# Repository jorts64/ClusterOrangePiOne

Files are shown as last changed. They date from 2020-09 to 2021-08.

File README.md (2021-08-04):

# Cluster Orange Pi One
Un Cluster [molt econòmic](bom.md) ( < 150 € ) utilitzant 7 [Orange Pi One](http://www.orangepi.org/orangepione/) amb [armbian](armbian.md). 

Aquest cluster el farem servir des d'un ordinador amb jupiter notebook

Utilitzem una torre vella de PC amb una font [ATX](img/ATX.jpg). Cada Orange Pi One va en una [safata](openscad/bandeja3p5OrangePiOne.stl) d'unitat 3.5" impressa en 3D dissenyada en [OpenSCAD](openscad/bandeja3p5OrangePiOne.scad) i té 6 leds connectats al seu connector [GPIO](img/OrangePiGpioConnector.png).

## Instal·lació a l'ordinador principal

Veure [instruccions](jupyter.md)

## Instal·lació a les plaques Orange Pi One

Cal fer 3 passos amb cada placa del cluster (canvieu el hostname *cluster1* per la placa que esteu treballant):

* Instal·lar armbian [Instruccions](armbian.md)
* Instal·lar les llibreries per treballar amb Jupyter [Instruccions](pythonlib.md)
* Instal·lar MPI [Instruccions](mpi4py.md)

També teniu disponible un [soport](openscad/ledsCluster.stl) pels 7 mòduls de leds dissenyat amb [openSCAD](openscad/ledsCluster.scad)

## Muntatge del conjunt

Podeu veure aquesta [galeria d'imatges](muntatge.md) del procés de muntatge

## Posada en funcionament

Una vegada tot a punt, he obert tres terminals a l'ordinador principal:

1r terminal: iniciem controlador del cluster

    ./clusterM

2n terminal: iniciem serveis computació paral·lela a les targetes Orange Pi One

    ./clusterS

3r terminal: iniciem Jupyter notebook

    cd ~/jupyter
    jupyter notebook

Jo he provat un [càlcul de pi pel mètode de Montecarlo](jupyter/parallel01.ipynb)    
Ha anat força bé: 320 millions de assatjos en 80s no es veu cada dia!

# Actualització agost 2021

Aquests dies de vacances he aprofitat per tornar al meu clúster d'orange pi. He afegit sortides de 5V i 12 V amb amperímetre, ventiladors, monitors de càrrega i de temperatura:

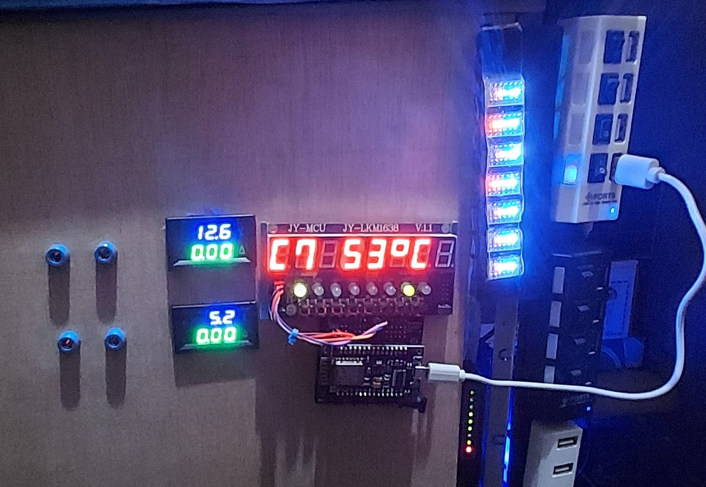
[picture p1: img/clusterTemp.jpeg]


## Monitors de càrrega
El programa [loadled.py](python3/loadled.py) es crida cada minut per [crontab](crontab/loadled) i actualitza els leds segons la càrrega de la placa orange pi.

## Monitor de temperatura
El programa [sendtemp](usrlocalbin/sendtemp) es crida cada minut per [crontab](crontab/sendtemp) i envia les dades a una placa NodeMCU ESP8266 programada amb codi [arduino](arduino/ClusterTemp.ino) amb una interfície basada en dígits de 7 segments, leds bicolors i polsadors.

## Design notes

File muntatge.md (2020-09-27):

# Muntatge del cluster

He fet servir una bella torre de PC amb font ATX. He afegit alguns connectors USB, sempre es necessiten! ( i el de color negre va a 5VSB, que sempre funciona fins-i-tot amb la font en standby)

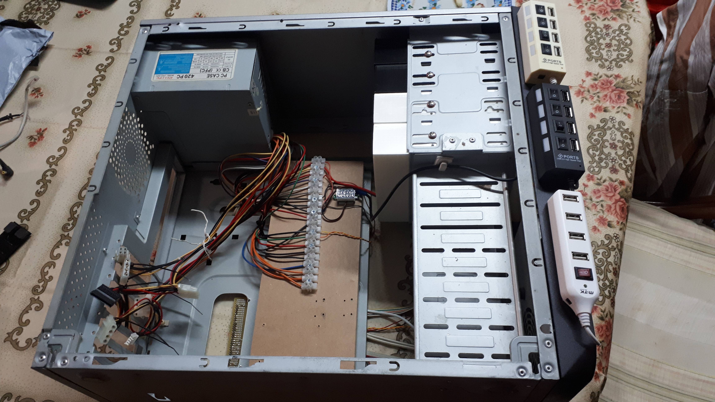
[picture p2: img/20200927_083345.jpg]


He tallat el connector de la motherboard i connectat els cables amb regletes de 10 A

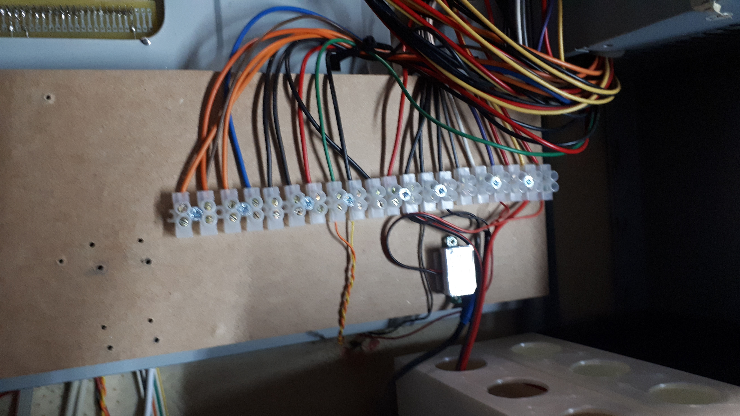
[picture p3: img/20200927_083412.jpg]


La font ens dona 36A a 5V, perfecte pel nostre projecte. Altres tensions seran útils per a altres usos de la capsa. Això si, caldra connectar un interruptor entre GND i el cable verd per controlar la font.

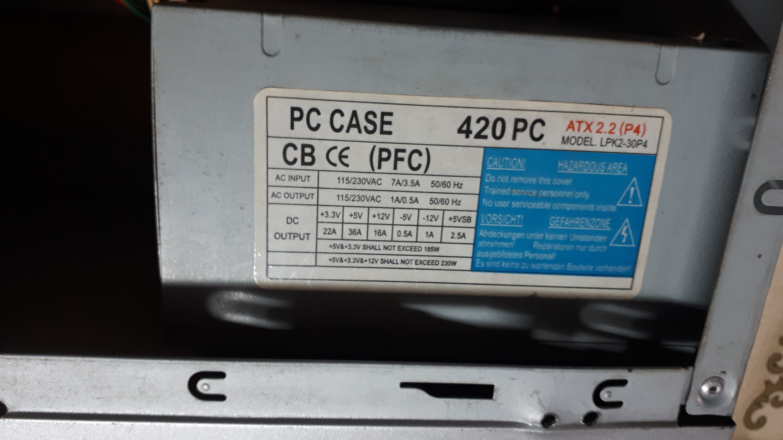
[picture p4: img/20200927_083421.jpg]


Cada placa Orange Pi One té el seu cable d'alimentació (que tallarem per connectar a la regleta) i la seva cinta per connectar el mòdul de leds.

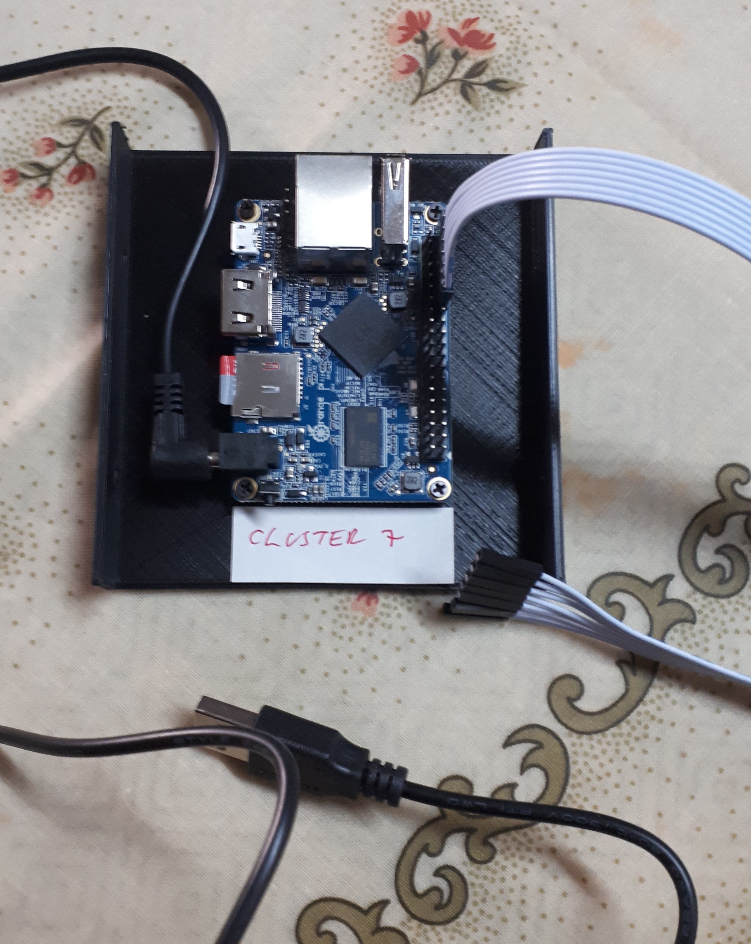
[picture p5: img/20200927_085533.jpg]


Els mòduls de leds van col·locats a una de les tapes, aquesta impressa en 3D

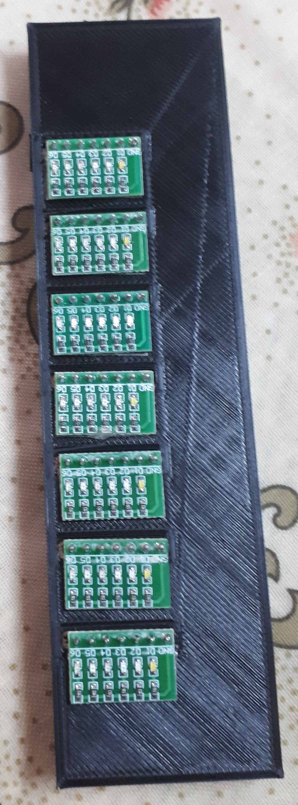
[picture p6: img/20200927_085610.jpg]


Preparem totes les plaques amb el programari instal·lat a la seva SD i els seus cables

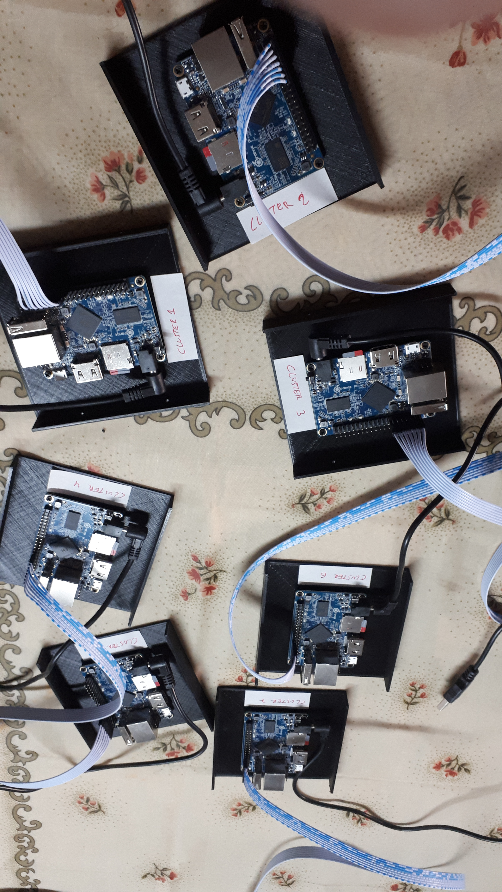
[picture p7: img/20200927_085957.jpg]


El switch va enganxat a una altra tapa, aquesta de fusta, amb cables de 1m

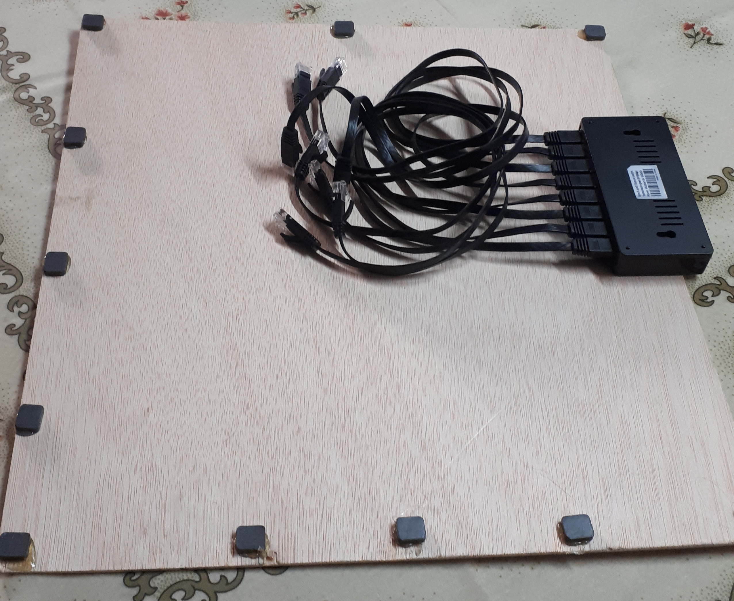
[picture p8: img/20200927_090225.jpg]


El switch sobresurt una mica de la tapa de fusta per mostrar els seus leds. També preparem un cable per connectar a 5V l'alimentació

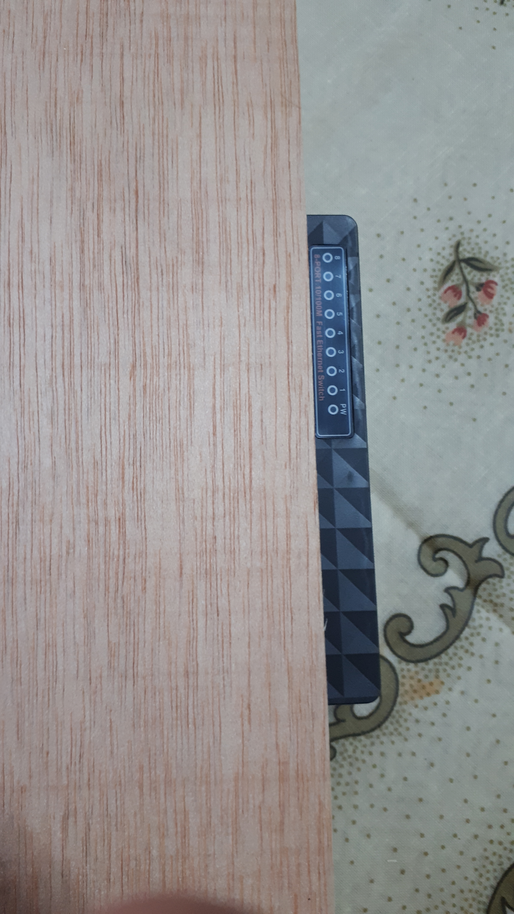
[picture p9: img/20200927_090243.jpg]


Connectem cada tarja al switch i fixem el conjunt amb cargols M3

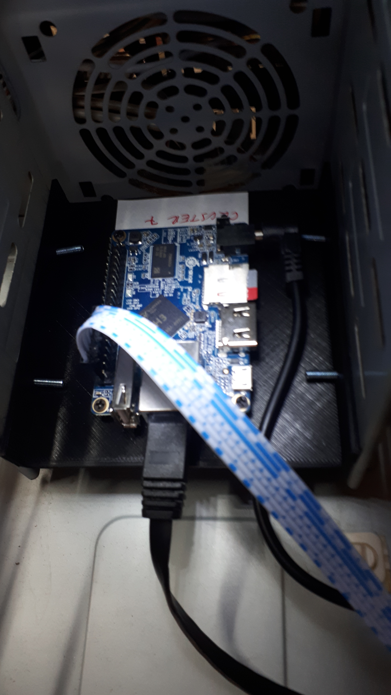
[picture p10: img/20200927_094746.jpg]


Connectem les alimentacions de les plaques i el switch en grups de 4 a les regletes (4x2A=8A < 10A)

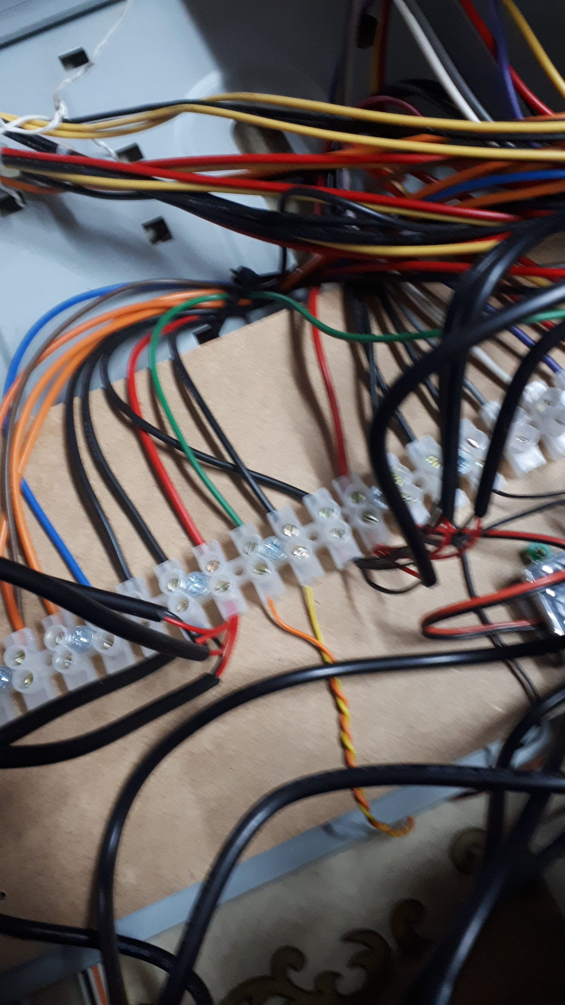
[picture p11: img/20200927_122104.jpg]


Una vegada fixades totes les plaques ordenem una mica el conjunt

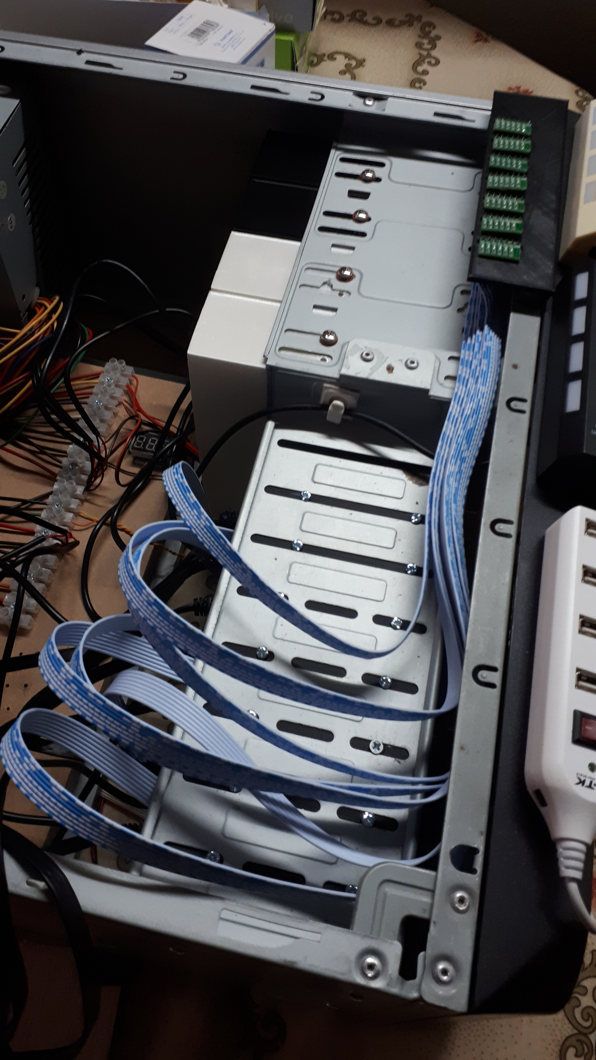
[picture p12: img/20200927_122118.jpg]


He aprofitat les bahies de 5" per posar uns calaixos impresos en 3D per a eines, i fins i tot una connexió de 12V per dremels i altres eines i instruments.

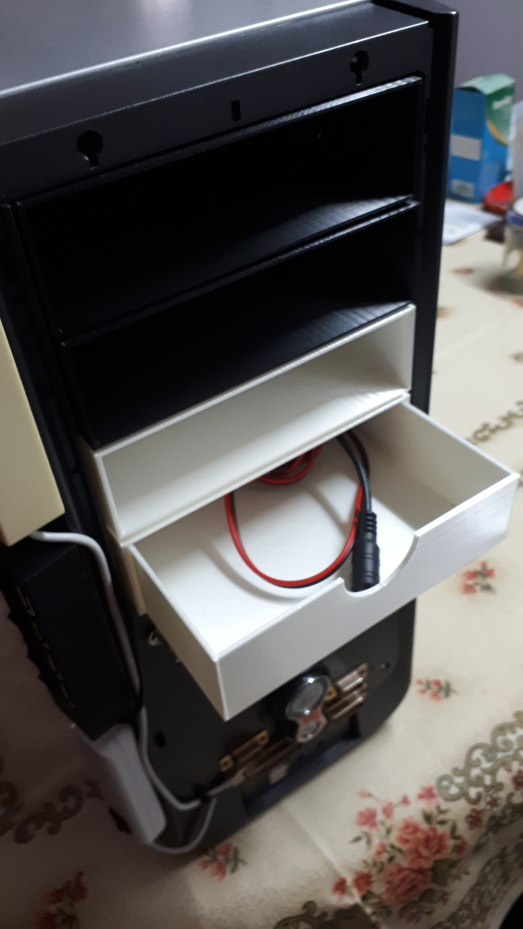
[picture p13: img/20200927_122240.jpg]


Finalment connectem a la xarxa i a 220V, engegem el sistema i tot funciona perfecte.

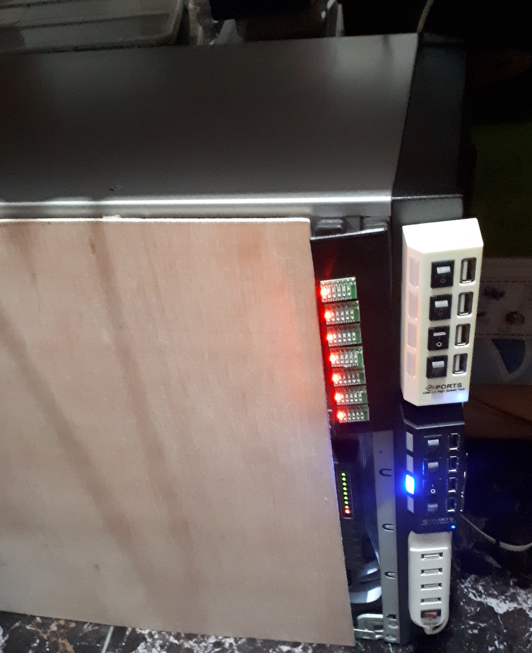
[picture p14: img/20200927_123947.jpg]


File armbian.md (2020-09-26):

# Instal·lació d'armbian a les plaques Orange Pi One

He utilitzat [armbian](https://www.armbian.com/orange-pi-one/) 20.05.2 basada en Buster (Debian 10), però baixant la versió actual hauria de funcionar igual.

Una vegada restaurada la imatge a una SD de 32 GB (jo he utilitzat l'eina Discs del meu Ubuntu) la posem a l'Orange Pi one i connectem la placa a la xarxa i aun carregador USB de 2A.

Localitzem a la xarxa quina IP ha agafat la placa (en el meu cas 192.168.1.136)

Ens connectem a la placa per xarxa des d'un terminal (contrasenya de *root* **1234**)

     ssh root@192.168.1.136

Ens obliga a canviar la contrasenya de *root* i crear un nou usuari. En el meu cas he creat l'usuari *jordi*, el mateix que faig servir a la meva màquina principal.

Actualitzem els paquets

     apt update
     apt upgrade

Instal·lem *mc*

    apt install mc

Configurem el sistema amb

    armbian-config
    
A *Personal settings -> Timezone* canviem el fus horari

A *Personal settings -> Hostname* canviem el nom de la màquina per *cluster1*

A *System -> Hardware* activem el bus GPIO **w1-gpio**

Reiniciem el sistema

    reboot
    
Ens tornem a connectar com a *root* i seguint les instruccions de [https://orangepiweb.es/gpio.php](https://orangepiweb.es/gpio.php) preparem el port GPIO per a python3:

    apt install python3-dev python3-setuptools swig python3-pip python3-wheel 
    git clone https://github.com/zhaolei/WiringOP.git -b h3
    cd WiringOP
    ./build
    cd ..
    git clone https://github.com/duxingkei33/orangepi_PC_gpio_pyH3.git
    cd orangepi_PC_gpio_pyH3/
    python3 setup.py install
    
Ara podem veure l'estat del GPIO amb 

    gpio readall

Però el nom dels pins que hem de fer servir amb aquesta llibreria de Python són aquests que veieu en color verd:

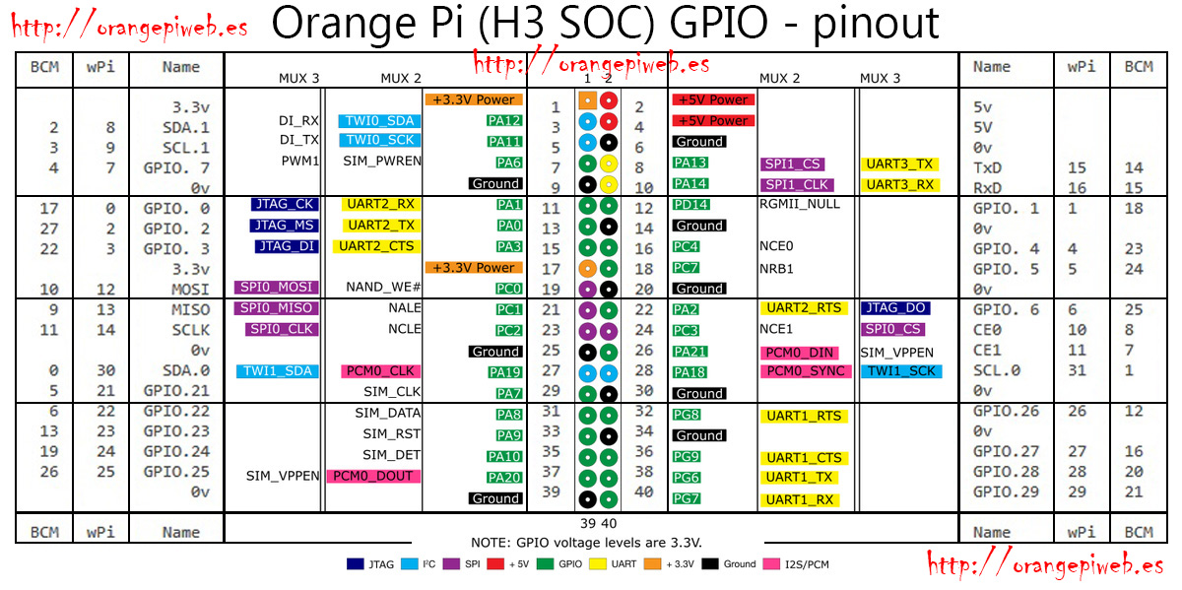
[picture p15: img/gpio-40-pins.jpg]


Ja podeu connectar el mòdul de 6 leds als pins senars 27-39 del connector i provar l'exemple [testleds.py](python3/testleds.py). Potser us caldrà abans fer una altra vegada reboot.

    cd ..
    wget https://raw.githubusercontent.com/jorts64/ClusterOrangePiOne/master/python3/testleds.py
    chmod u+x testleds.py
    ./testleds.py

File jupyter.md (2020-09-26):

# Instal·lació de jupyter notebook a l'ordinador principal

Aquesta instal·lació l'he comprovada amb Debian 10. és important escollir aquesta distribució per compatibilitat amb el cluster, ja que no dona problemes de comunicació MPI amb Armbian.

Primer instal·lem les biblioteques científiques, després jupyter:

    sudo apt install python3-pip
    sudo python3 -m pip install --upgrade pip
    sudo pip3 install sympy
    sudo apt-get install python3-matplotlib
    sudo apt-get install python3-scipy -y
    sudo apt-get install python3-numpy -y
    sudo pip3 install jupyter

També interessa instal·lar Latex, ja que ens permetrà exportar el nostre document a PDF

    sudo apt-get install texlive-xetex texlive-fonts-recommended texlive-generic-recommended

Ara ja podrem crear una carpeta a l'usuari que executarà el servidor jupyter per desar els arxius, i executarem des d'aquesta carpeta jupyter, que obrira un navegador amb el webide

    mkdir ~/jupyter
    cd ~/jupyter
    jupyter notebook

Si el volem tenir a un servidor, caldrà evitar que intenti obrir el navegador i haurem d'autoritzar el seu ús des d'altres màquines a la xarxa

Primer hem de crear un fitxer de configuració

    jupyter notebook --generate-config

Aquest fitxer el trobarem a ~/.jupyter/jupyter_notebook_config.py. L'haurtem de modificar amb les línies

    c.NotebookApp.open_browser = False
    c.NotebookApp.ip = '*'

I haurem de generar una contrasenya per evitar treballar amb tokens

    jupyter notebook password

Ara ja podem crear a l'ordinador principal un fitxer  [~/myhostfile](bash/myhostfile) con las IPs de los servidores i quants programes executaran simultàniament

També crearem un parell de claus ssh en aquest ordinador amb:

    ssh-keygen

deixant els valors per defecte (ENTER a totes les preguntes). Farem una còpia de la clave pública amb el nom main:

    cd .ssh
    cp id_rsa.pub main

Instal·lem mpi, que ens permetrà executar ordres remotes:

    sudo apt install openmpi-bin python3-mpi4py -y

Per treballar amb el cluster caldrà configurar Jupyter notebook

    sudo ipcluster nbextension enable
    jupyter serverextension enable --py ipyparallel
    jupyter nbextension install --py ipyparallel
    jupyter nbextension enable --py ipyparallel

I copiar els executables [clusterM](bash/clusterM) i [clusterS](bash/clusterS) per iniciar el cluster i que caldrà adaptar al vostre cluster (nom d'usuari, IPs on copiar arxiu de seguretat, nombre de slots disponibles)

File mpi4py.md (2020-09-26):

# Preparació MPI per Python

**Important: Totes les operacions d'aquest document es faran amb l'usuari creat, no amb root**

Abans de continuar cal fixar la IP de la Orange Pi One. Jo ho he fet des del meu router, però es pot fer d'altres formes, fins-i-tot amb armbian-config.

També instal·larem openmpi-bin python3-mpi4py a les targetes Orange Pi One del cluster i generarem la parella de claus ssh.  Crearem una còpia de la clau pública del client en la carpeta .ssh del servidor (en el meu cas el servidor té la IP 192.168.1.60):

    sudo apt install openmpi-bin python3-mpi4py -y
    ssh-keygen
    cd .ssh
    cp id_rsa.pub  cluster1
    scp 192.168.1.60:/home/jordi/.ssh/main .
    cat main>>authorized_keys

A l'ordinador principal també haurem de copiar les claus públiques de les targetes Orange Pi One i afegir-les a les autoritzades:

En el meu cas la tarjeta Orange Pi One té la IP 192.168.1.136:

    scp 192.168.1.136:/home/jordi/.ssh/cluster1 .
    cat cluster1>>authorized_keys

Ara ja podem provar el funcionament (en el meu cas tinc un total de 12 slots disponibles en aquest moment) amb:

    mpirun -hostfile myhostfile -np 12 hostname

També caldrà instal·lar en les targetes Orange Pi One el processament paral·lel en Python3:

    sudo apt install pkg-config libzmq3-dev
    sudo pip3 install ipyparallel

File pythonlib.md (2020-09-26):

# Instal·lació de les llibreries python3 per als  jupyter notebook al cluster

Caldrà instal·lar totes aquelles llibreries de python3 que neessitin els nostres programes. Jo he provat amb una instal·lacio inicial de:

    sudo apt-get install python3-matplotlib python3-scipy python3-numpy -y
    sudo pip3 install sympy cython

Pero sempre podrem instal·lar qualsevol més remotament.

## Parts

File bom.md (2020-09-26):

7x [10P Dupont Cable 60CM Jumper Wire Line Female to Female 600mm For Arduino](https://www.aliexpress.com/item/4000484342034.html?spm=a2g0s.9042311.0.0.f3344c4dQHPR7R) = 3€

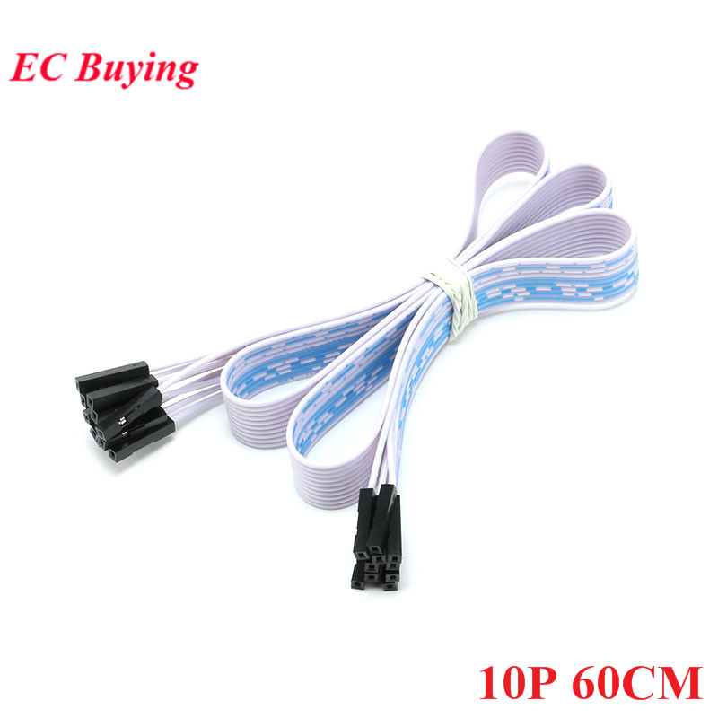
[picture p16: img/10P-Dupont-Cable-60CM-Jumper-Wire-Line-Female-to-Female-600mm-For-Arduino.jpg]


1x [10pack 0.5m cable CAT6 Flat UTP Ethernet Network Cable RJ45 Patch LAN cable](https://www.aliexpress.com/item/32970493291.html?spm=a2g0s.9042311.0.0.f3344c4dQHPR7R) = 9€

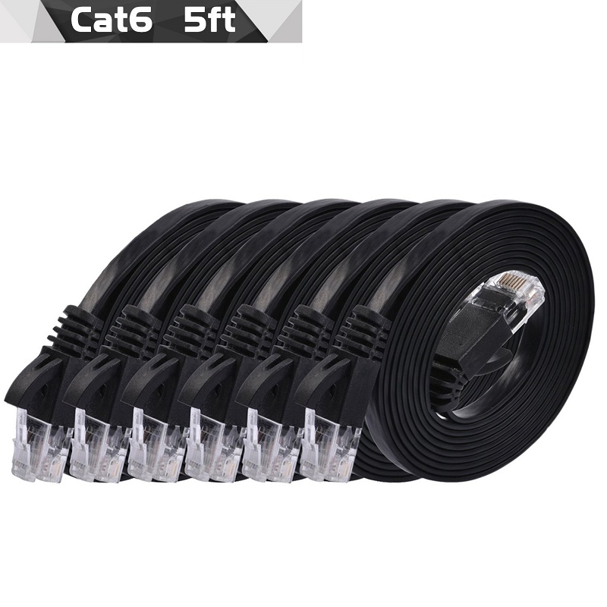
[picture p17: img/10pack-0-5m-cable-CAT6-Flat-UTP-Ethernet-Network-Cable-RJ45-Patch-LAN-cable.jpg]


7x [100% Original SanDisk Micro SD Card Class10 TF Card 16gb 32gb 64gb 128gb Max 98Mb/s memory card for samrtphone and table PC](https://www.aliexpress.com/item/32690158317.html?spm=a2g0s.9042311.0.0.f3344c4dQHPR7R) = 27€

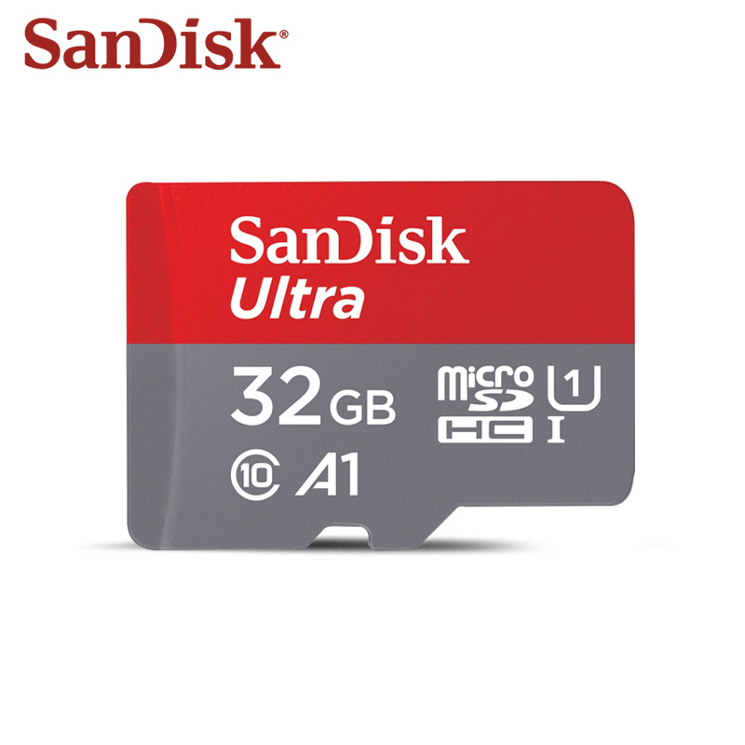
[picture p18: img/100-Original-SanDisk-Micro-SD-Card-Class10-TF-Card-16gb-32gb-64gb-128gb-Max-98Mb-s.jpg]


7x [Orange Pi One H3 512MB Quad-core Support ubuntu linux and android mini PC](https://www.aliexpress.com/item/32603308880.html?spm=a2g0s.9042311.0.0.f3344c4dQHPR7R) = 70€

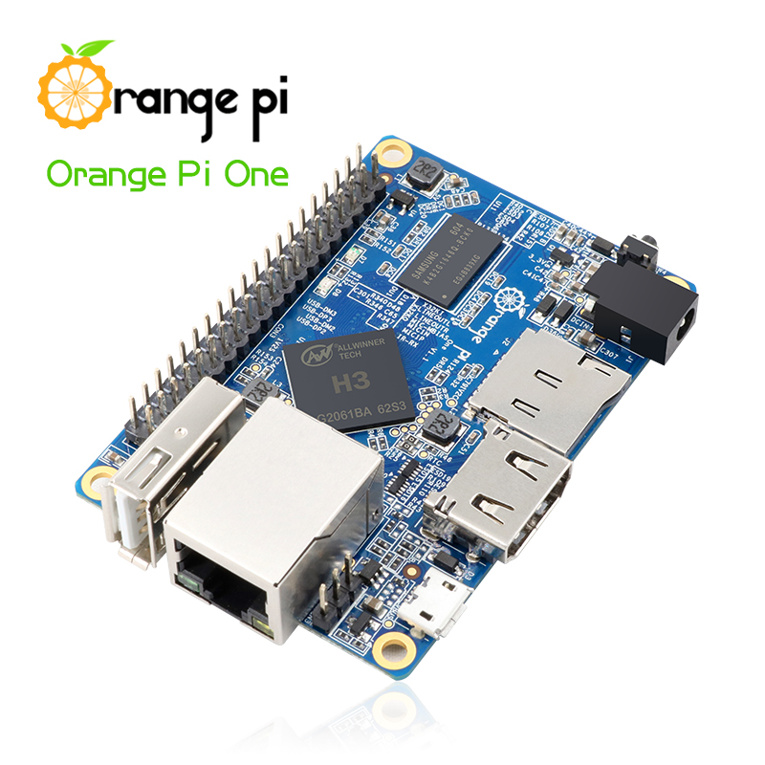
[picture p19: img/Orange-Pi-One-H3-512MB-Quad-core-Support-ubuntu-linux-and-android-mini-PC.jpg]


1x [kebidumei Network Switch 8 Ports 10/100Mbps Fast Ethernet RJ45 Switcher Lan Hub MDI Full/Half duplex exchange AC Prower Adapter](https://www.aliexpress.com/item/32825979338.html?spm=a2g0s.9042311.0.0.f3344c4dQHPR7R) = 7€

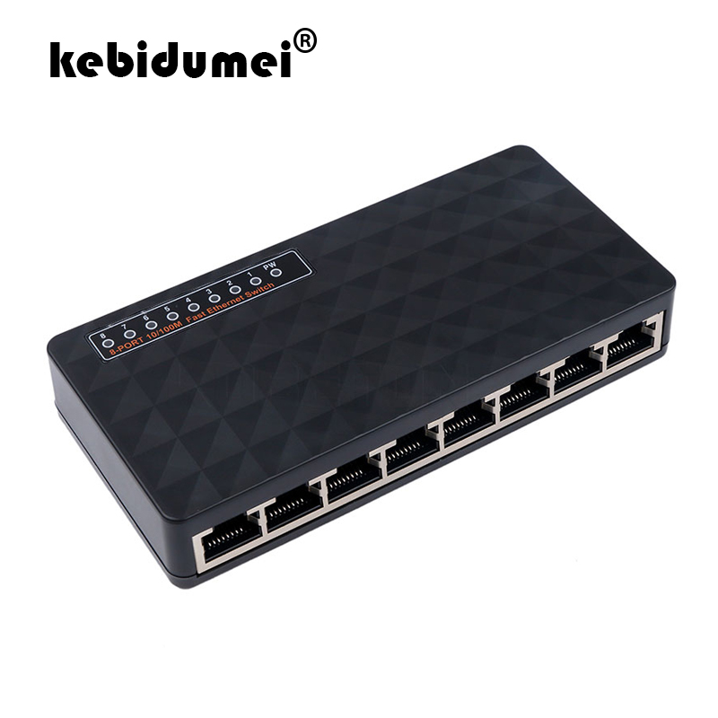
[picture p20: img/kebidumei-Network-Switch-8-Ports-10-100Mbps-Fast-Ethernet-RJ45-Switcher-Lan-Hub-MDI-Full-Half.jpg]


7x [DC Power Plug USB Convert To 4.0*1.7mm/DC 4.0x1.7 White Black L Shape Right Angle Jack With Cord Connector Cable](https://www.aliexpress.com/item/4000192579563.html?spm=a2g0s.9042311.0.0.1ec64c4d3fT5TA) = 8€

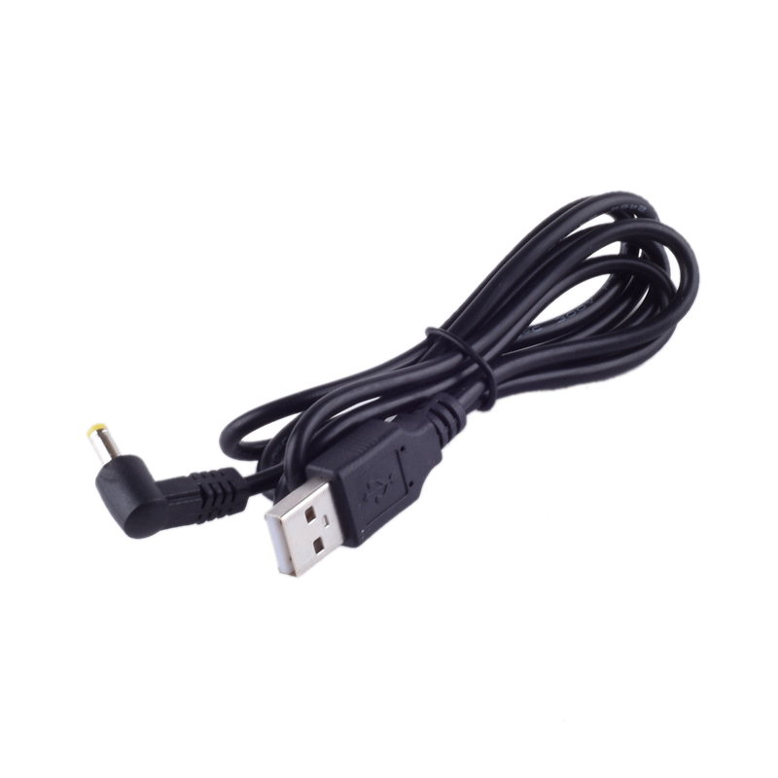
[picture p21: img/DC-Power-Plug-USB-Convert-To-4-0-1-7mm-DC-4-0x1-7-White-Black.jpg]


2x [5pcs DC 3-12V 6 bit Multicolor LED Module Board for Arduino DUE UNO MEGA2560 MEGA Leonardo Tre Zero Ethernet Shield 3d printer](https://www.aliexpress.com/item/32275491062.html?spm=a2g0s.9042311.0.0.1ec64c4d3TEkPW) = 7€

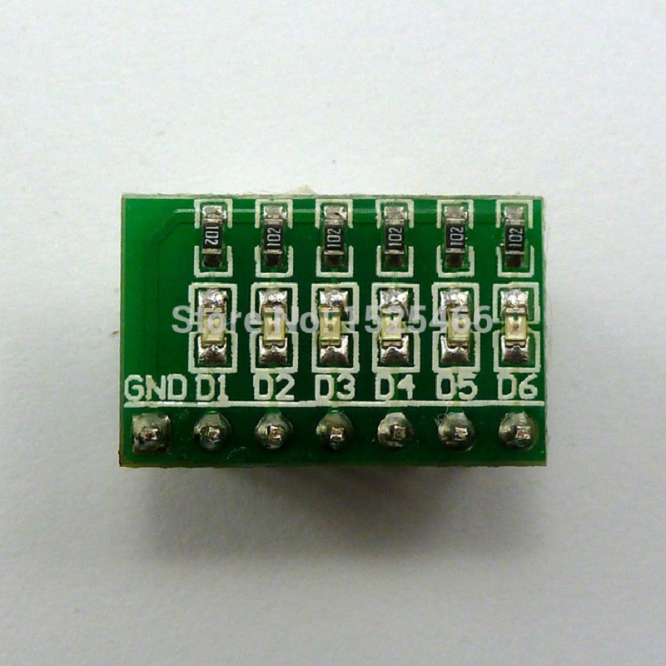
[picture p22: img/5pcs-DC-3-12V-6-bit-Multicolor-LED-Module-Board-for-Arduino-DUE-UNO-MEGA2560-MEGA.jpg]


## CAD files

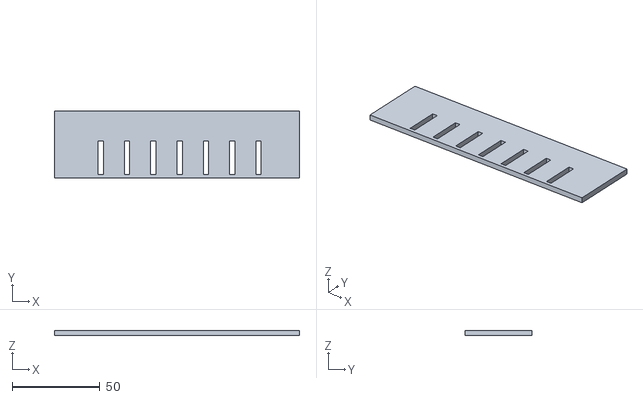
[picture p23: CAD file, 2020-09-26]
openscad/ledsCluster.stl
140.0 x 38.0 x 3.00

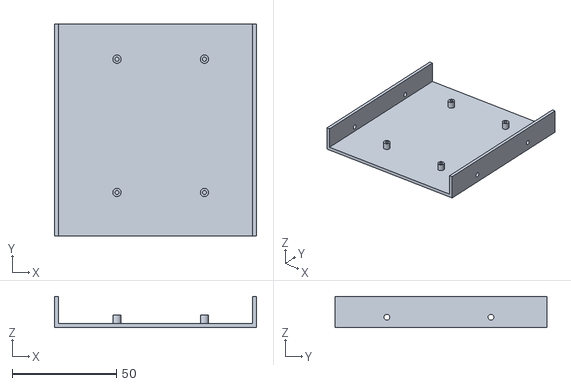
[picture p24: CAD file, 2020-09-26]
openscad/bandeja3p5OrangePiOne.stl
97.0 x 102.0 x 15.0

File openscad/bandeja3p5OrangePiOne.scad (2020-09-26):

difference(){
    cube([97,102,15]);
    union(){
        translate([2,-1,2]) cube([93,104,23]);
        translate ([-1,25,5]) rotate ([0,90,0]) cylinder(r=1.4,h=5, $fn=48); 
        translate ([-1,75,5]) rotate ([0,90,0]) cylinder(r=1.4,h=5, $fn=48); 
        translate ([95,25,5]) rotate ([0,90,0]) cylinder(r=1.4,h=5, $fn=48); 
        translate ([95,75,5]) rotate ([0,90,0]) cylinder(r=1.4,h=5, $fn=48); 
    }

}
translate([30,21,1]) difference(){
    cylinder(r=2, h=5, $fn=96);
    cylinder(r=1, h=5, $fn=96);  
}
translate([30,85,1]) difference(){
    cylinder(r=2, h=5, $fn=96);
    cylinder(r=1, h=5, $fn=96);  
}
translate([72,21,1]) difference(){
    cylinder(r=2, h=5, $fn=96);
    cylinder(r=1, h=5, $fn=96);  
}
translate([72,85,1]) difference(){
    cylinder(r=2, h=5, $fn=96);
    cylinder(r=1, h=5, $fn=96);  
}

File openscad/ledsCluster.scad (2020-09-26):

difference() {
    cube([140,38,3]);
    for( x = [25 : 15 : 115])
       translate([x,2,-1]) cube([3,19,5]);

}

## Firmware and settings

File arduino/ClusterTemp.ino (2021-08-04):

#include <TM1638.h>
#include <ESP8266WiFi.h>
#include <WiFiClient.h>
#include <ESP8266WebServer.h>

// define a module on data pin 8, clock pin 9 and strobe pin 7
TM1638 module(D5, D6, D7);

const char *ssid = "NOMDEXARXA";
const char *password = "CONTRASENYA";

ESP8266WebServer server ( 80 );

int temp[7];
bool ciclo;
int maq;
char s[8];
int led;

void espera(int temps) {
  unsigned long ara = millis();
  unsigned long seguent = ara + temps;
  delay(1); //refresh watchdog
  while (millis()<seguent){
      server.handleClient();
  }
}

void canviar_temp() {
  int m,t;
  m = server.arg("maq").toInt();
  t = server.arg("temp").toInt();
  temp[m]=t;
  server.send(200, "text/html", "ok"); 
}

void setup() {
  temp[0]=51;
  temp[1]=52;
  temp[2]=53;
  temp[3]=54;
  temp[4]=55;
  temp[5]=56;
  temp[6]=57;
  ciclo = true;
  maq = 0;
  Serial.begin(115200);
  WiFi.begin ( ssid, password );
  Serial.println("");

  // Wait for connection
  while (WiFi.status() != WL_CONNECTED) {
    delay(500);
    Serial.print(".");
  }
  Serial.println("");
  Serial.print("Connected to ");
  Serial.println(ssid);
  Serial.print("IP address: ");
  Serial.println(WiFi.localIP());
  
  server.on("/changeT", canviar_temp); 
  server.begin();

  sprintf(s, "CLUSTERT");
  module.setDisplayToString(s);
  espera(300);
  module.clearDisplay();
}

void loop() {
  sprintf(s, "C%01d %d^C", maq+1, temp[maq]);
  module.setDisplayToString(s);
  if (ciclo) {
    led = 1 << maq+8;
  }
  else {
    led = 1 << maq;
  }
  module.setLEDs(led);

  byte keys = module.getButtons();
  switch (keys) {
    case 0x80:
      ciclo = true;
      break;
    case 0x40:
      ciclo = false;
      maq = 6;
      break;
    case 0x20:
      ciclo = false;
      maq = 5;
      break;
    case 0x10:
      ciclo = false;
      maq = 4;
      break;
    case 0x8:
      ciclo = false;
      maq = 3;
      break;
    case 0x4:
      ciclo = false;
      maq = 2;
      break;
    case 0x2:
      ciclo = false;
      maq = 1;
      break;
    case 0x1:
      ciclo = false;
      maq = 0;
      break;
  }

  if(ciclo) {
    maq++;
    if(maq>6) maq=0;
  }
  espera(500);
}

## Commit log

2020-09-26 fitxer nou: img/100-Original-SanDisk-Micro-SD-Card-Class10-TF-Card-16gb-32gb-64gb-128gb-Max-98Mb-s.jpg fitxer nou: img/10P-Dupont-Cable-60CM-Jumper-Wire-Line-Female-to-Female-600mm-For-Arduino.jpg fi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
    [bandeja3p5OrangePiOne.scad, bandeja3p5OrangePiOne.stl]
2020-09-26 fitxer nou: openscad/ledsCluster.scad fitxer nou: openscad/ledsCluster.stl
    [ledsCluster.scad, ledsCluster.stl]
2021-07-31 Create loadled.py
    Carrega del sistema als leds
2021-07-31 Create loadled
    actualitza leds cada minut
2021-08-04 Update README.md
    Inclou monitors de càrrega i monitor de temperatura
